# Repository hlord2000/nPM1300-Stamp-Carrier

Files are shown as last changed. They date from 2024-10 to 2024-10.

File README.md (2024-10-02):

# nPM1300 Stamp Carrier Board

<p align="center">
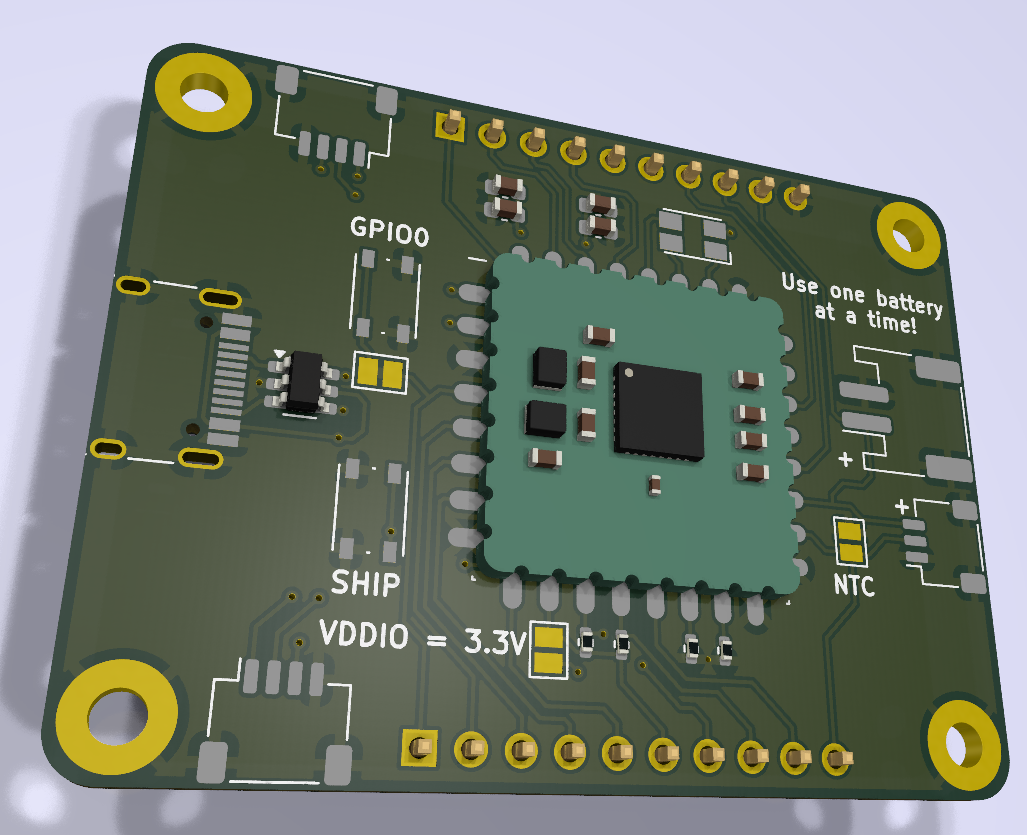
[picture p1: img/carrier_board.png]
nPM1300 Stamp Carrier Board
  
</p>

## Overview

Companion carrier board for the nPM1300 Stamp, providing additional functionality and connectivity options. Designed for rapid prototyping and development with the nPM1300 PMIC.

## Key Features

- USB-C port for power
- ESD protection
- Ship mode button
- User button on GPIO0
- Two STEMMA QT ports
- Pin headers for all nPM1300 Stamp connections
- RGB LED
- JST-PH and JST-SH battery connectors
- Configurable solder jumpers

## Design Resources

- Schematic available
- PCB design files available

## Solder Jumper Options

- VDDIO source selection
- NTC thermistor bypass
- Load switch to LDO conversion

## Usage Notes

- Compatible with nPM1300 Stamp
- Provides all external components required by nPM1300
- I2C pull-ups included
- ESD protection provided for USB-C and battery connections

For detailed specifications of the nPM1300, visit [Nordic Semiconductor's nPM1300 page](https://www.nordicsemi.com/Products/nPM1300).

For information about the nPM1300 Stamp, see the [nPM1300 Stamp Repository](https://github.com/hlord2000/nPM1300-Stamp).

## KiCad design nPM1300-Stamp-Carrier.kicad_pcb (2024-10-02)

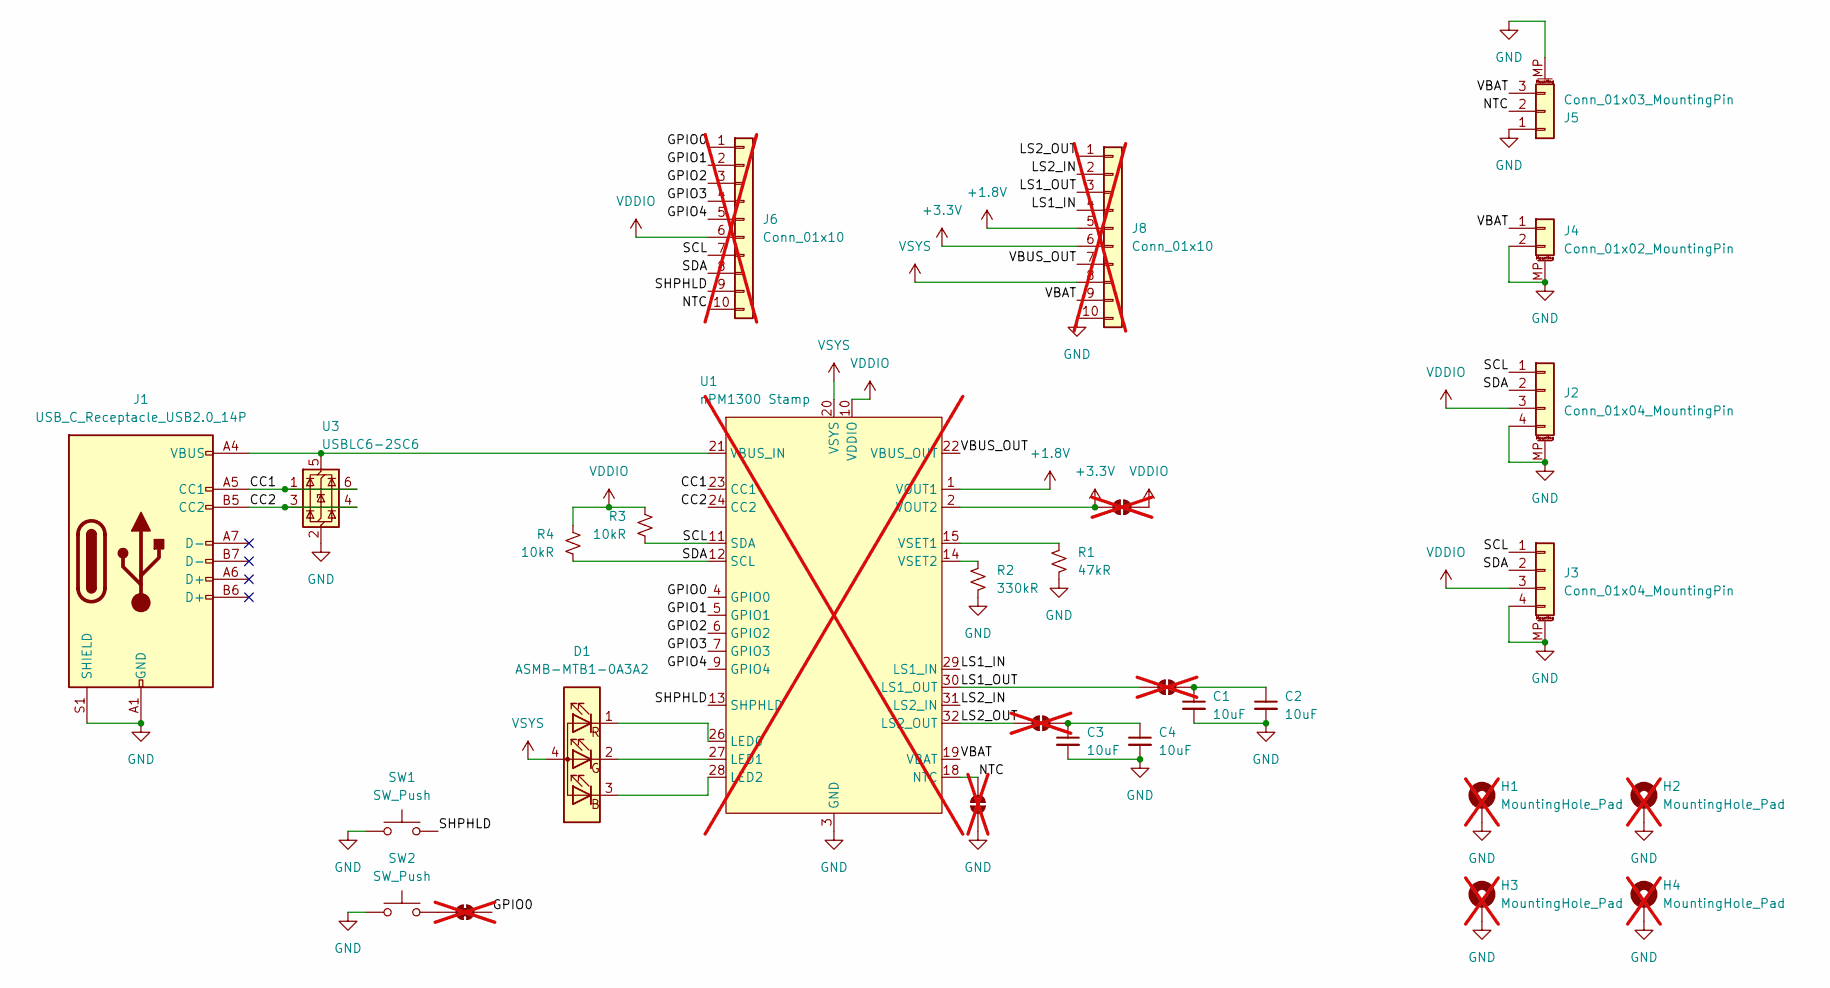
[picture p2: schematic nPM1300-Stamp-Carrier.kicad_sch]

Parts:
C1, C2, C3, C4: 10uF; C_0603_1608Metric; LCSC C96446
D1: ASMB-MTB1-0A3A2; LED_Avago_PLCC4_3.2x2.8mm_CW; LCSC C516144
H1, H2, H3, H4: MountingHole_Pad; MountingHole_2.5mm_Pad_TopBottom; not fitted
J1: USB_C_Receptacle_USB2.0_14P; USB_C_Receptacle_HRO_TYPE-C-31-M-12; LCSC C2765186
J2, J3: Conn_01x04_MountingPin; JST_SH_SM04B-SRSS-TB_1x04-1MP_P1.00mm_Horizontal; LCSC C7433425
J4: Conn_01x02_MountingPin; JST_PH_S2B-PH-SM4-TB_1x02-1MP_P2.00mm_Horizontal; LCSC C3029440
J5: Conn_01x03_MountingPin; JST_SH_SM03B-SRSS-TB_1x03-1MP_P1.00mm_Horizontal; LCSC C7433424
J6, J8: Conn_01x10; PinHeader_1x10_P2.54mm_Vertical; not fitted
JP1, JP2, JP3, JP4: SolderJumper_2_Open; SolderJumper-2_P1.3mm_Open_Pad1.0x1.5mm; not fitted
JP5: SolderJumper_2_Bridged; SolderJumper-2_P1.3mm_Bridged_Pad1.0x1.5mm; not fitted
R1: 47kR; R_0402_1005Metric; LCSC C25792
R2: 330kR; R_0402_1005Metric; LCSC C25778
R3, R4: 10kR; R_0402_1005Metric; LCSC C25744
SW1, SW2: SW_Push; SW_Push_1P1T_NO_Vertical_Wuerth_434133025816; LCSC C139797
U1: nPM1300 Stamp; nPM1300-Stamp_18x18_Pitch2mm; not fitted
U3: USBLC6-2SC6; SOT-23-6; LCSC C5180249

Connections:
+1.8V: J8.5, U1.1 (VOUT1)
+3.3V: J8.6, JP4.2 (B), U1.2 (VOUT2)
/CC1: J1.A5 (CC1), U1.23 (CC1), U3.1 (I/O1), U3.6 (I/O1)
/CC2: J1.B5 (CC2), U1.24 (CC2), U3.3 (I/O2), U3.4 (I/O2)
/GPIO0: J6.1, JP5.2 (B), U1.4 (GPIO0)
/GPIO1: J6.2, U1.5 (GPIO1)
/GPIO2: J6.3, U1.6 (GPIO2)
/GPIO3: J6.4, U1.7 (GPIO3)
/GPIO4: J6.5, U1.9 (GPIO4)
/LS1_IN: J8.4, U1.29 (LS1_IN)
/LS1_OUT: J8.3, JP1.2 (B), U1.30 (LS1_OUT)
/LS2_IN: J8.2, U1.31 (LS2_IN)
/LS2_OUT: J8.1, JP2.2 (B), U1.32 (LS2_OUT)
/NTC: J5.2, J6.10, JP3.1 (A), U1.18 (NTC)
/SCL: J2.1, J3.1, J6.7, R3.2, U1.11 (SDA)
/SDA: J2.2, J3.2, J6.8, R4.2, U1.12 (SCL)
/SHPHLD: J6.9, SW1.2, U1.13 (SHPHLD)
/VBAT: J4.1, J5.3, J8.9, U1.19 (VBAT)
/VBUS_OUT: J8.7, U1.22 (VBUS_OUT)
GND: C1.2, C2.2, C3.2, C4.2, H1.1, H2.1, H3.1, H4.1, J1.A1 (GND), J1.A12 (GND), J1.B1 (GND), J1.B12 (GND), J1.S1 (SHIELD), J2.4, J2.MP (MountPin), J3.4, J3.MP (MountPin), J4.2, J4.MP (MountPin), J5.1, J5.MP (MountPin), J8.10, JP3.2 (B), R1.2, R2.2, SW1.1, SW2.1, U1.3 (GND), U1.8 (GND), U1.16 (GND), U1.17 (GND), U1.25 (GND), U3.2 (GND)
unnamed: D1.3 (BK), U1.28 (LED2)
unnamed: D1.2 (GK), U1.27 (LED1)
unnamed: D1.1 (RK), U1.26 (LED0)
unnamed: C1.1, C2.1, JP1.1 (A)
unnamed: C3.1, C4.1, JP2.1 (A)
unnamed: JP5.1 (A), SW2.2
unnamed: J1.A4 (VBUS), J1.A9 (VBUS), J1.B4 (VBUS), J1.B9 (VBUS), U1.21 (VBUS_IN), U3.5 (VBUS)
unnamed: R1.1, U1.15 (VSET1)
unnamed: R2.1, U1.14 (VSET2)
VDDIO: J2.3, J3.3, J6.6, JP4.1 (A), R3.1, R4.1, U1.10 (VDDIO)
VSYS: D1.4 (A), J8.8, U1.20 (VSYS)

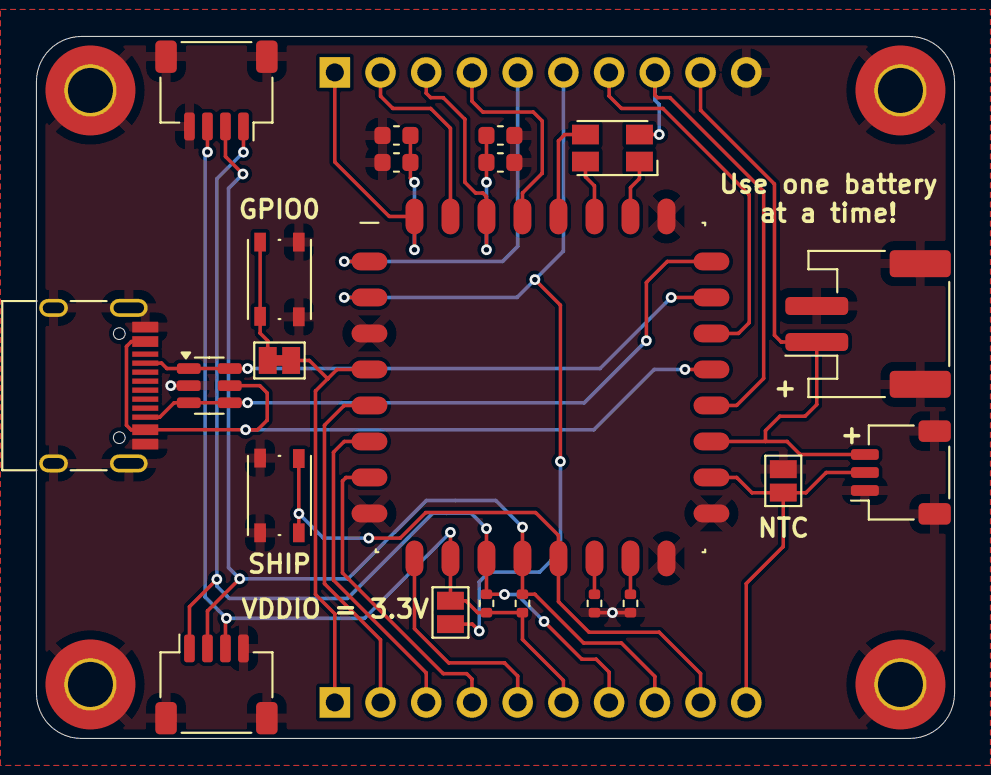
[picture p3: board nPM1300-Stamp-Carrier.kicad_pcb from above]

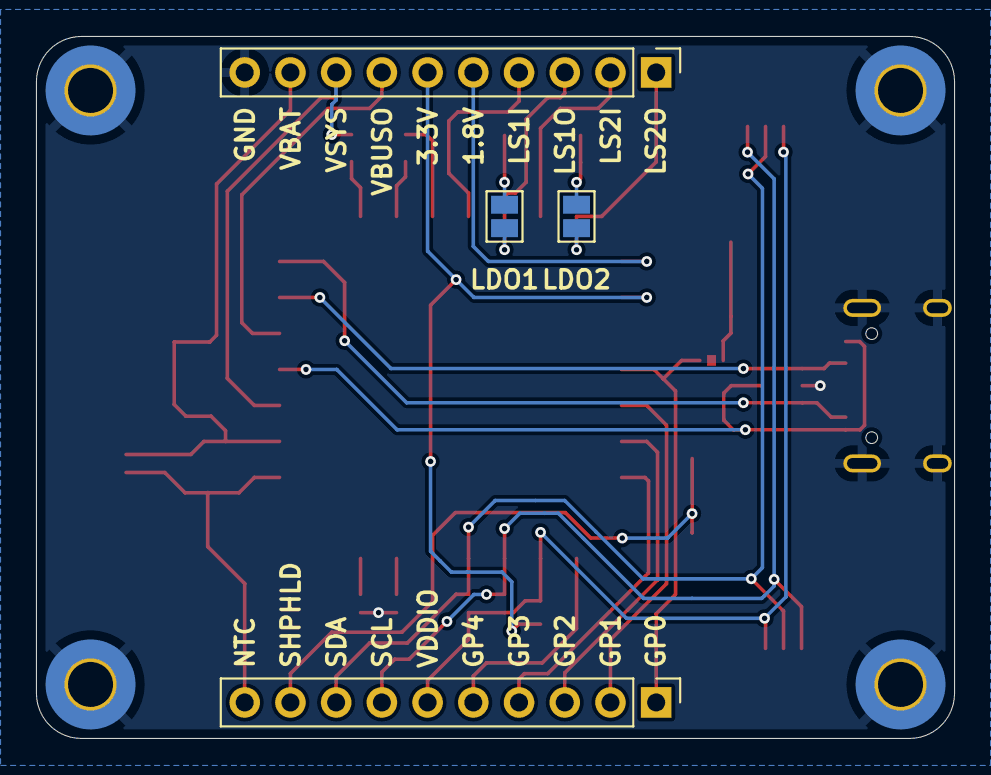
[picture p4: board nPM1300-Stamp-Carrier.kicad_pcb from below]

Board: 2 copper layers, 51.0 x 39.0 mm, 29 parts (4 on the bottom side), 31 nets.
